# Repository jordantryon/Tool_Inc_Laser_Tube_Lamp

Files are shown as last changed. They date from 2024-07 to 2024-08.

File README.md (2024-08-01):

# Tool., Inc - Laser Tube Lamp
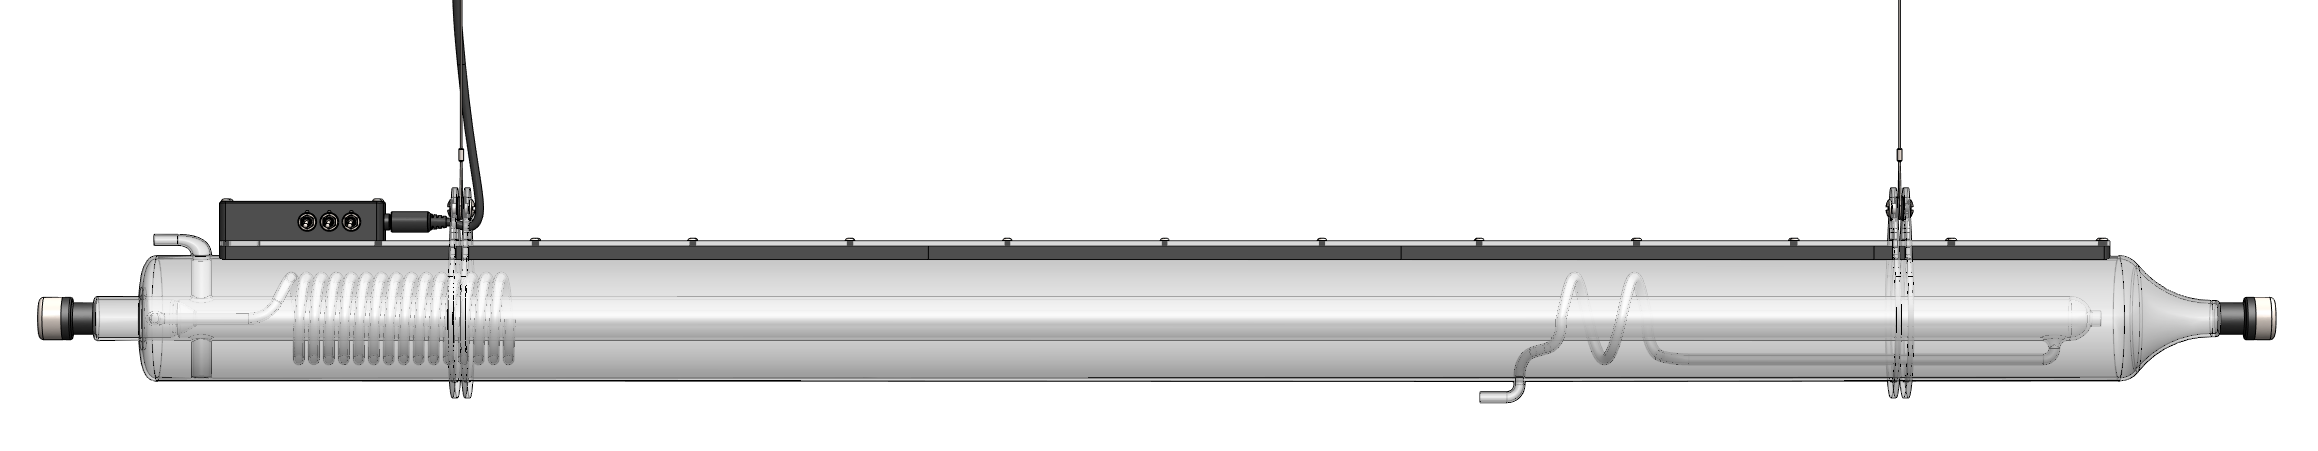
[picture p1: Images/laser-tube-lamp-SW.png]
Laser Tube Lamp SolidWorks


At [Tool., Inc.](https://toolinc.com/) our engineers and designers are constantly using our Lasersaur CNC laser cutter/engraver. Usually to rapidly produce project prototypes but occasionally to make furniture and pieces around the office. Unfortunately, the laser tube that makes the magic happen slowly degrades over time and needs to be replaced. So, what do you do with the old dead tube? It looks super cool so it feels bad to just throw it away. Why not turn it into a unique light fixture?! 

With the new laser tube installed in the machine, we cut a handful of 1/8" acrylic parts and got our Ultimaker 3D printers going on some PLA components. All the hardware is fairly standard and can be found at a local hardware store, or every mechanical engineer's favorite: McMaster-Carr. Using an Arduino and Adafruit NeoPixels, any light can go from plain white to fully custom and dynamic RGB lighting effects in the flick of a switch. Ours uses three toggle switches to select from up to eight preprogrammed lighting modes. We enlisted one of our summer interns to help turn the lighting animations into the 1s and 0s. 

Combine all that with an old 120W, 80mm diameter, 1450mm long, CO2 laser tube and you get a, slightly less destructive, 25W LED lamp. It makes a perfect addition to any shop, makerspace, studio, or employee kitchen and lounge. 

We've open-sourced the project so you too can DIY the most expensive lamp in your shop! This GitHub repository has the instructions, bill of materials, CAD files, and source code. The design was based around our laser tube and equipment but you can adjust it to fit your needs. 

## Lighting Modes
|Switch C|Switch B|Switch A|Mode|
|:---|:---|:---|:---|
|0|0|0|Off|
|0|0|1|Cool White|
|0|1|0|Warm White|
|0|1|1|Wave Bounce|
|1|0|0|Laser Build|
|1|0|1|Breathing Cycle|
|1|1|0|Fill Cycle|
|1|1|1|Rainbow Slide|

## Bill of Materials

### 3D Prints

|Part|File|Quantity|
|:---|:---|:---|
|Electronics Enclosure|electronics_enclosure.stl|1|
|Hanger Cable Pulley|hanger_cable_pully.stl|2|
|Strip (End)|strip_end.stl|2|
|Strip (Side)|strip_side.stl|6|

### Laser Cuts

|Part|File|Quantity|
|:---|:---|:---|
|Strip Backing|strip_back.dxf|1|
|Teardrop Hanger|teardrop_hanger.dxf|4|

### Hardware

|Part|SKU|Quantity|Link|
|:---|:---|:---|:---|
|M3 Heat Set Inserts|94459A140|26|[McMaster-Carr](https://www.mcmaster.com/94459A140/)|
|M3 x 8 mm Button Head Hex Drive Screw|92095A181|22|[McMaster-Carr](https://www.mcmaster.com/92095A181/)|
|M3 x 30 mm Button Head Hex Drive Screw|92095A187|4|[McMaster-Carr](https://www.mcmaster.com/92095A187/)|
|Binding Barrel|98002A202|2|[McMaster-Carr](https://www.mcmaster.com/98002A202/)|
|Wire Rope|3461T474|1|[McMaster-Carr](https://www.mcmaster.com/3461T474/)|
|Wire Rope Compression Sleeve|3896T61|4|[McMaster-Carr](https://www.mcmaster.com/3896T61/)|
|Foam Double Face Mounting Tape|3744A41|1|[McMaster-Carr](https://www.mcmaster.com/3744A41/)|

### Electronics

|Part|SKU|Quantity|Link|Notes|
|:---|:---|:---|:---|:---|
|Arduino Nano Every|ABX00028|1|[Arduino](https://store.arduino.cc/products/arduino-nano-every)|I'd recommend getting the version without headers to solder directly to the Arduino.|
|DC Power Supply (5V, 5A)|B078RT3ZPS|1|[Amazon](https://a.co/d/07ThTM0f)|Each NeoPixel can draw up to 60 mA. For my strip length, that's 4.26 amps!|
|DC Barrel Jack|B07CTCLKPP|1|[Amazon](https://a.co/d/05rNLqdA)||
|Toggle Switch|100SP1T1B1M1QEH|3|[DigiKey](https://www.digikey.com/en/products/detail/e-switch/100SP1T1B1M1QEH/378819)||
|NeoPixel Strip (2 m)|2540|1|[Adafruit](https://www.adafruit.com/product/2540)|To save a couple bucks, buying two 1 m strips can be cheaper.|
|Resistor (470 Ω)|CF14JT470R|1|[DigiKey](https://www.digikey.com/en/products/detail/stackpole-electronics-inc/CF14JT470R/1741440)||
|Capacitor (1,000 μF)|ECA-0JM102|1|[DigiKey](https://www.digikey.com/en/products/detail/panasonic-electronic-components/ECA-0JM102/244974)||

## Images
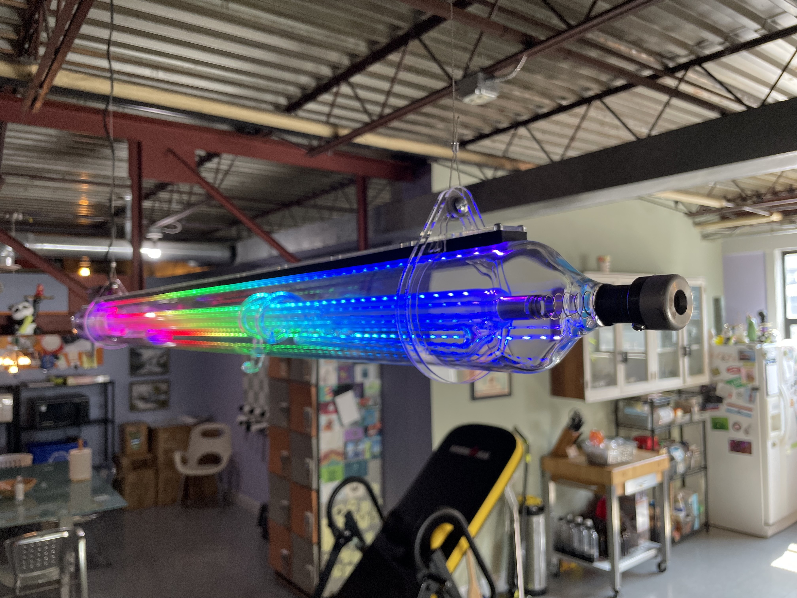
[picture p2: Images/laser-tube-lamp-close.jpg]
Laser Tube Lamp SolidWorks

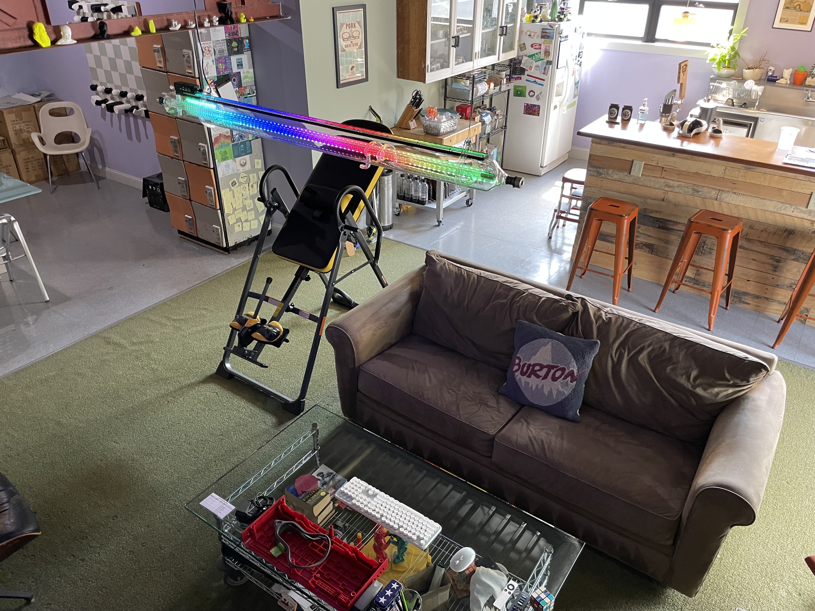
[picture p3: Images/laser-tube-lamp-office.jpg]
Laser Tube Lamp SolidWorks


## Author
Jordan Tryon for tool., Inc.

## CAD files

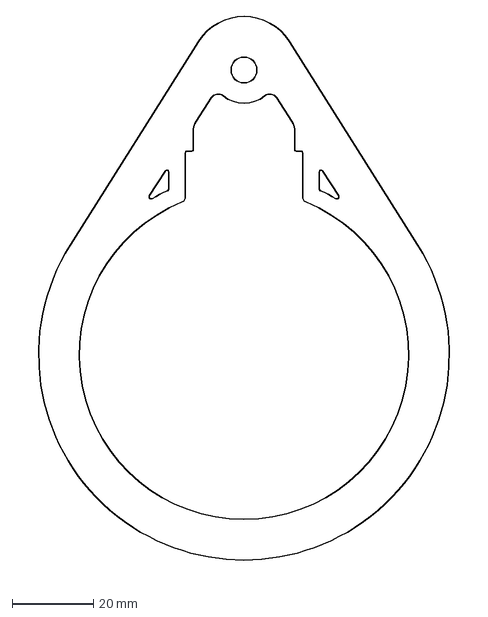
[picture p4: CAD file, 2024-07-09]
DXFs/teardrop_hanger.DXF
112.1 x 137.8 mm

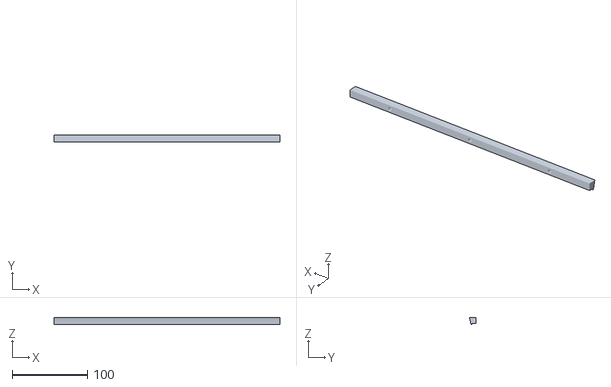
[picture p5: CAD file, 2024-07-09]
STLs/strip_side.STL
300.0 x 8.78 x 9.50

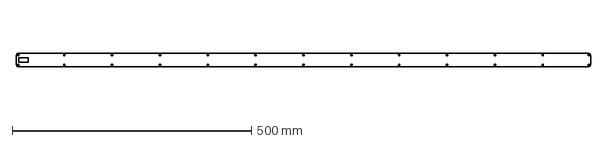
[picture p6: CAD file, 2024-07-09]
DXFs/strip_back.DXF
1200.0 x 28.0 mm

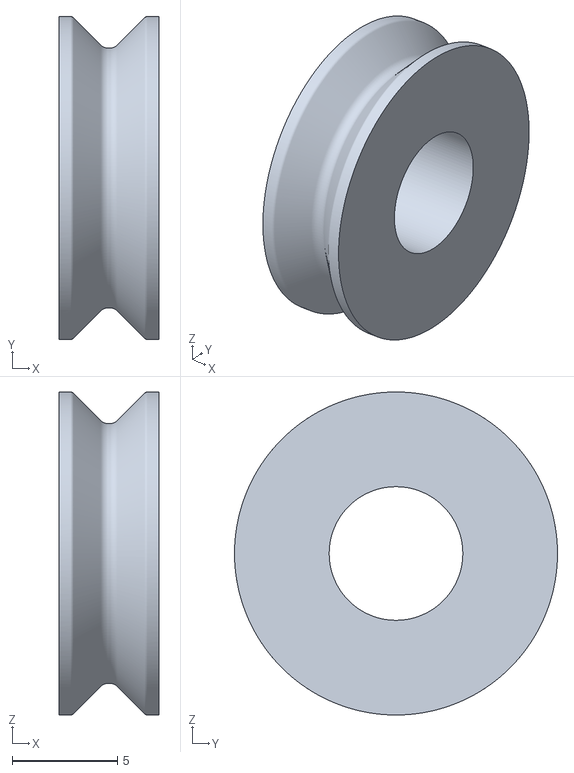
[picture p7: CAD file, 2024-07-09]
STLs/hanger_cable_pully.STL
4.76 x 15.4 x 15.3

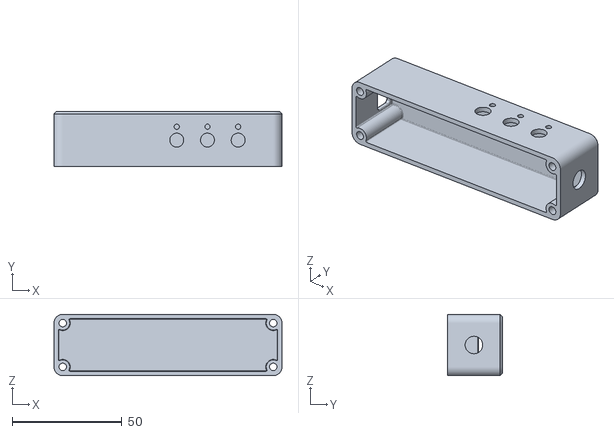
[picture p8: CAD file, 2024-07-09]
STLs/electronics_enclosure.STL
104.0 x 25.0 x 28.0

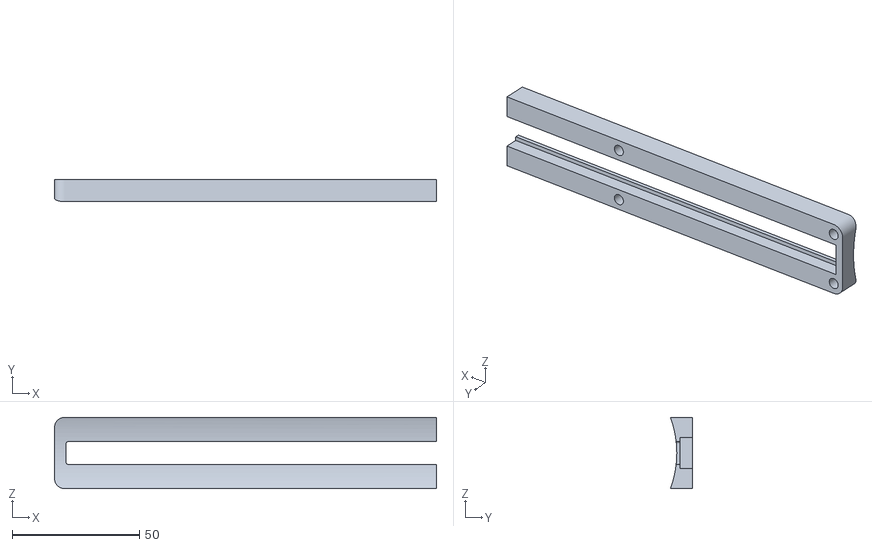
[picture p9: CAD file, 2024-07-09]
STLs/strip_end.STL
150.0 x 8.78 x 28.0

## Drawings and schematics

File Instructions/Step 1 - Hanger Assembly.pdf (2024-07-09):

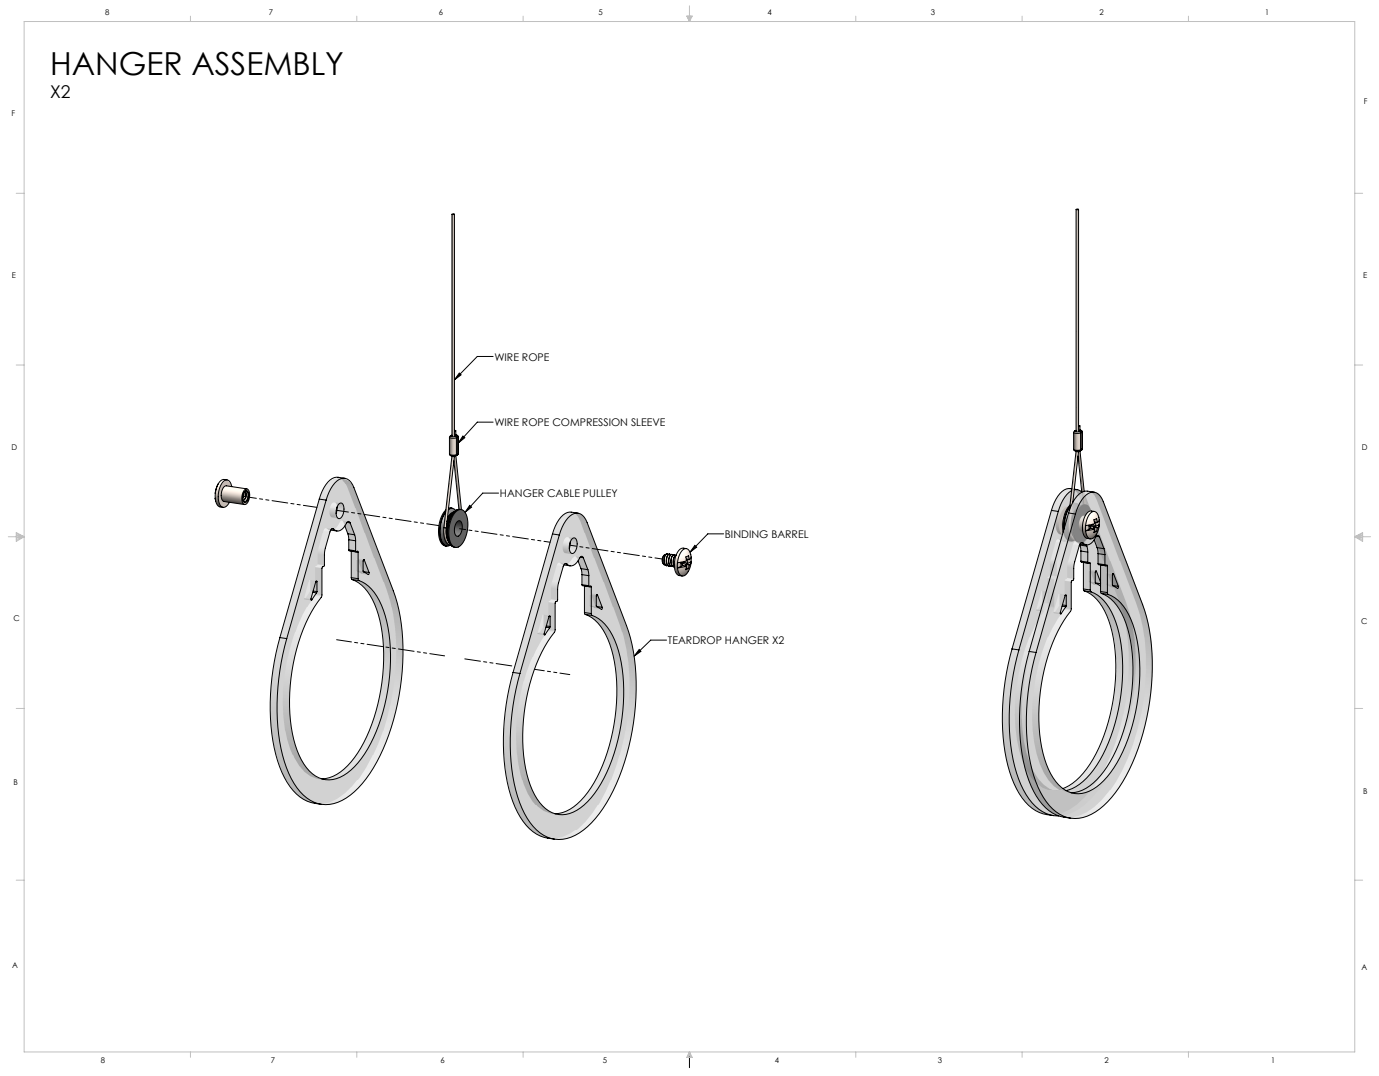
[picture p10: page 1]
WIRE ROPE; BINDING BARREL; TEARDROP HANGER X2; HANGER ASSEMBLY

WIRE ROPE COMPRESSION SLEEVE

HANGER CABLE PULLEY

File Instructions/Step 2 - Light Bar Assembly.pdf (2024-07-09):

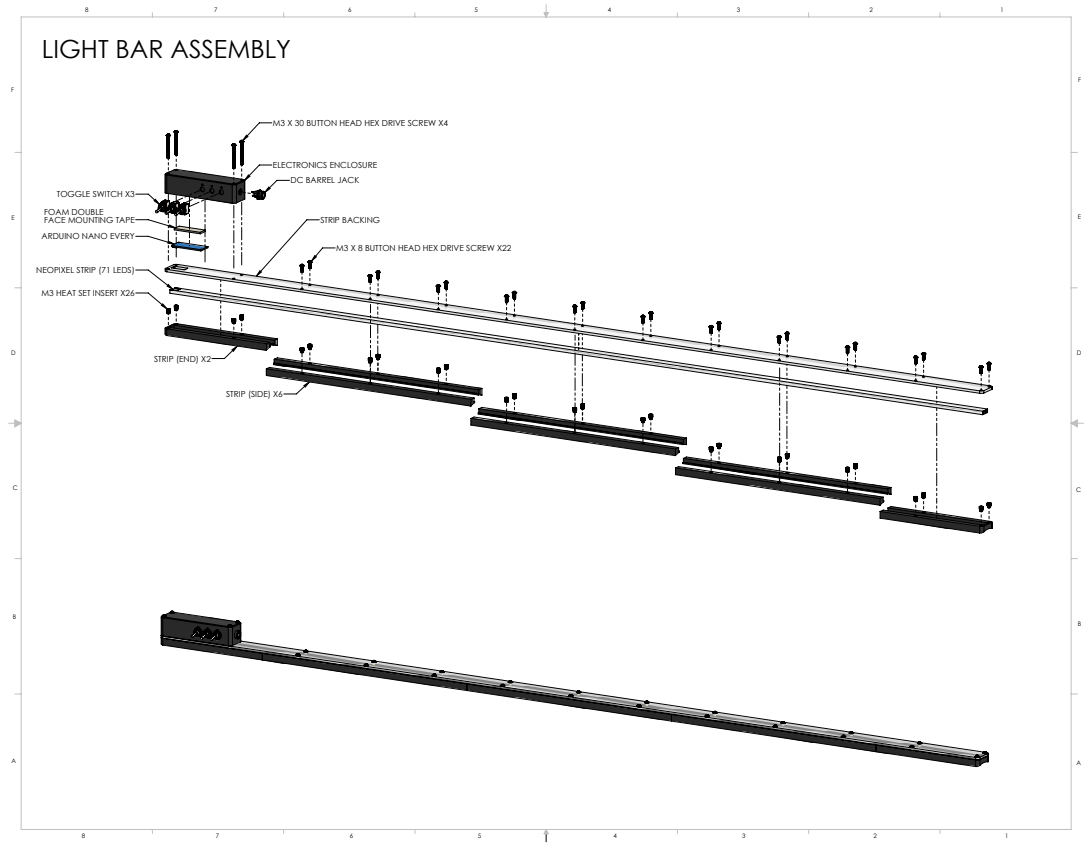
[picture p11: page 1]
STRIP BACKING; STRIP (SIDE) X6; STRIP (END) X2

LIGHT BAR ASSEMBLY

M3 X 30 BUTTON HEAD HEX DRIVE SCREW X4

ELECTRONICS ENCLOSURE
DC BARREL JACK

TOGGLE SWITCH X3
FOAM DOUBLE
FACE MOUNTING TAPE
ARDUINO NANO EVERY

M3 X 8 BUTTON HEAD HEX DRIVE SCREW X22

NEOPIXEL STRIP (71 LEDS)

M3 HEAT SET INSERT X26

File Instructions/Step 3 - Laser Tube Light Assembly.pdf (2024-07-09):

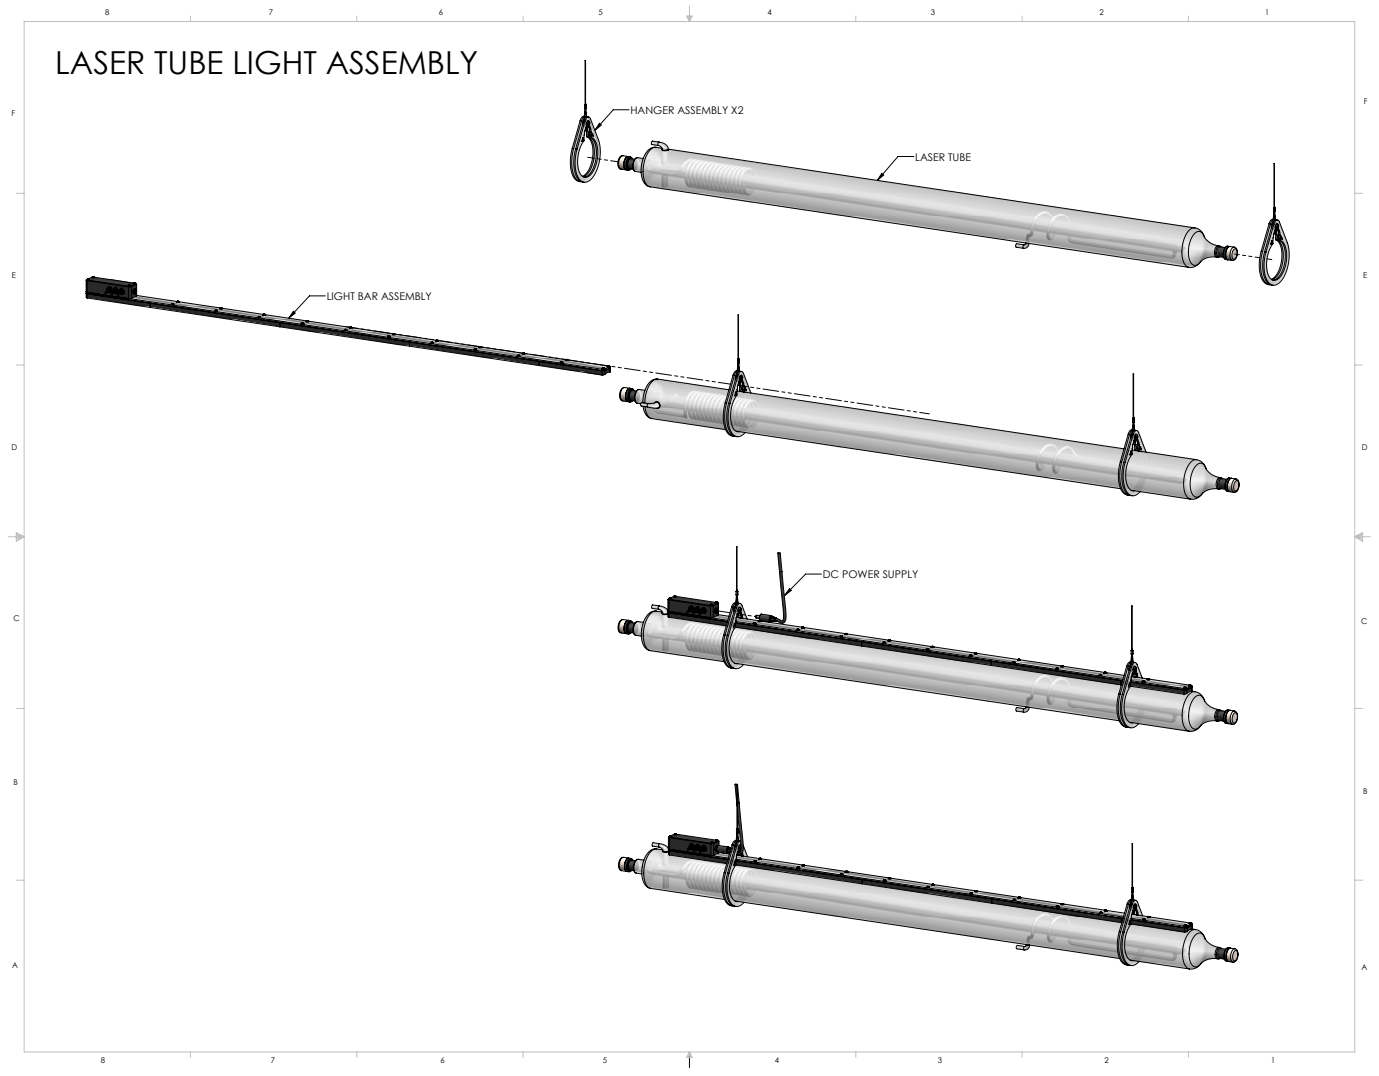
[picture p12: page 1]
HANGER ASSEMBLY X2; LASER TUBE

LASER TUBE LIGHT ASSEMBLY

LIGHT BAR ASSEMBLY

DC POWER SUPPLY

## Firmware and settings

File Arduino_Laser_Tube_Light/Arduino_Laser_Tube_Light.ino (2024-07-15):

// Author: Jordan Tryon - tool., Inc.
// Modified: 7/15/2024
// Project: Laser Tube Light
// Description: Arduino code for controlling a NeoPixel strip lighting fixture. 

// -------------------------------------- INCLUDE LIBRARIES -------------------------------------- //

#include <Adafruit_NeoPixel.h>

// --------------------------------------- PIN DEFINITIONS --------------------------------------- //

// Define input pins
#define pin_switch_a 2
#define pin_switch_b 3
#define pin_switch_c 4

// Define NeoPixel strip pin
#define pin_neopixel 5

// -------------------------------------- PROGRAM VARIABLES -------------------------------------- //

// Button & Switch Inputs
const int debounce_time = 10;

// NeoPixel
const int num_pixels = 71;
Adafruit_NeoPixel strip(num_pixels, pin_neopixel, NEO_GRB + NEO_KHZ800);

// Control
bool val_a = LOW;
bool val_b = LOW;
bool val_c = LOW;

// ----------------------------------- STATE MACHINE VARIABLES ----------------------------------- //

int state_switch_a = 2;
int state_switch_b = 2;
int state_switch_c = 2;

// ------------------------------------- Timers & Timestamps ------------------------------------- //

unsigned long t = 0;
unsigned long t_0 = 0;
unsigned long t_switch_a = 0;
unsigned long t_0_switch_a = 0;
unsigned long t_switch_b = 0;
unsigned long t_0_switch_b = 0;
unsigned long t_switch_c = 0;
unsigned long t_0_switch_c = 0;

// ----------------------------------------- SETUP LOOP ------------------------------------------ //

void setup(){
  // Wait for initial power-on
  delay(1000);
  
  // Initialize input pins
  pinMode(pin_switch_a, INPUT);
  pinMode(pin_switch_b, INPUT);
  pinMode(pin_switch_c, INPUT);

  // Initialize the NeoPixel object
  strip.begin();
  strip.setBrightness(255);
  strip.clear();
  strip.show();
  
  // Begin serial communication
  Serial.begin(115200);
}

// ---------------------------------------- PROGRAM LOOP ----------------------------------------- //

void loop(){
  // Wait to update the lighting mode, prevents repeatedly calling blocking functions after switches change position
  t_0 = millis();
  t = millis();
  while(t - t_0 <= 20){
    t = millis();
    SM_switch_a();
    SM_switch_b();
    SM_switch_c();
  }

  // Off
  if(val_c == LOW && val_b == LOW && val_a == LOW){
    strip.clear();
    strip.show();
  }

  // On - Cool White
  if(val_c == LOW && val_b == LOW && val_a == HIGH){
    strip_fill(255, 255, 255);
  }

  // On - Warm White
  if(val_c == LOW && val_b == HIGH && val_a == LOW){
    strip_fill(255, 100, 10);
  }

  // On - Wave Bounce
  if(val_c == LOW && val_b == HIGH && val_a == HIGH){
    wave_bounce(255, 100, 10);
  }

  // On - Laser Build
  if(val_c == HIGH && val_b == LOW && val_a == LOW){
    laser_build(255, 100, 10);
  }

  // On - Breathing Cycle
  if(val_c == HIGH && val_b == LOW && val_a == HIGH){
    breathing_cycle();
  }

  // On - Fill Cycle
  if(val_c == HIGH && val_b == HIGH && val_a == LOW){
    fill_cycle();
  }

  // On - Rainbow Slide
  if(val_c == HIGH && val_b == HIGH && val_a == HIGH){
    rainbow_slide();
  }
}

// --------------------------------------- STATE MACHINES ---------------------------------------- //

// State machine to debounce switch a
void SM_switch_a(){
  bool currentVal = digitalRead(pin_switch_a);
  
  switch(state_switch_a){
    case 0: // 0 - Wait for LOW
      if(currentVal == LOW){
        t_0_switch_a = millis();
        state_switch_a = 1;
      }
    break;
    
    case 1: // 1 - Debounce
      t_switch_a = millis();
      if(currentVal == HIGH){ state_switch_a = 0; }
      if(t_switch_a - t_0_switch_a >= debounce_time){ state_switch_a = 2; }
    break;
    
    case 2: // 2 - Trigger LOW
      val_a = LOW;
      state_switch_a = 3;
    break;
    
    case 3: // 3 - Wait for HIGH
      if(currentVal == HIGH){
        t_0_switch_a = millis();
        state_switch_a = 4;
      }
    break;
    
    case 4: // 4 - Debounce
      t_switch_a = millis();
      if(currentVal == LOW){ state_switch_a = 3; }
      if(t_switch_a - t_0_switch_a >= debounce_time){ state_switch_a = 5; }
    break;
    
    case 5: // 5 - Trigger HIGH
      val_a = HIGH;
      state_switch_a = 0;
    break;
    
    default:
    break;
  }
}

// State machine to debounce switch b
void SM_switch_b(){
  bool currentVal = digitalRead(pin_switch_b);
  
  switch(state_switch_b){
    case 0: // 0 - Wait for LOW
      if(currentVal == LOW){
        t_0_switch_b = millis();
        state_switch_b = 1;
      }
    break;
    
    case 1: // 1 - Debounce
      t_switch_b = millis();
      if(currentVal == HIGH){ state_switch_b = 0; }
      if(t_switch_b - t_0_switch_b >= debounce_time){ state_switch_b = 2; }
    break;
    
    case 2: // 2 - Trigger LOW
      val_b = LOW;
      state_switch_b = 3;
    break;
    
    case 3: // 3 - Wait for HIGH
      if(currentVal == HIGH){
        t_0_switch_b = millis();
        state_switch_b = 4;
      }
    break;
    
    case 4: // 4 - Debounce
      t_switch_b = millis();
      if(currentVal == LOW){ state_switch_b = 3; }
      if(t_switch_b - t_0_switch_b >= debounce_time){ state_switch_b = 5; }
    break;
    
    case 5: // 5 - Trigger HIGH
      val_b = HIGH;
      state_switch_b = 0;
    break;
    
    default:
    break;
  }
}

// State machine to debounce switch c
void SM_switch_c(){
  bool currentVal = digitalRead(pin_switch_c);
  
  switch(state_switch_c){
    case 0: // 0 - Wait for LOW
      if(currentVal == LOW){
        t_0_switch_c = millis();
        state_switch_c = 1;
      }
    break;
    
    case 1: // 1 - Debounce
      t_switch_c = millis();
      if(currentVal == HIGH){ state_switch_c = 0; }
      if(t_switch_c - t_0_switch_c >= debounce_time){ state_switch_c = 2; }
    break;
    
    case 2: // 2 - Trigger LOW
      val_c = LOW;
      state_switch_c = 3;
    break;
    
    case 3: // 3 - Wait for HIGH
      if(currentVal == HIGH){
        t_0_switch_c = millis();
        state_switch_c = 4;
      }
    break;
    
    case 4: // 4 - Debounce
      t_switch_c = millis();
      if(currentVal == LOW){ state_switch_c = 3; }
      if(t_switch_c - t_0_switch_c >= debounce_time){ state_switch_c = 5; }
    break;
    
    case 5: // 5 - Trigger HIGH
      val_c = HIGH;
      state_switch_c = 0;
    break;
    
    default:
    break;
  }
}

// ------------------------------------------ FUNCTIONS ------------------------------------------ //

void strip_fill(int r, int g, int b){
  for(int i = 0; i < num_pixels; i++){
    strip.setPixelColor(i, strip.Color(r, g, b));
  }
  strip.show();
}

void fill_cycle(){
  fill_cycle(10);
}

void fill_cycle(unsigned long d){
  int r = 255;
  int g = 0;
  int b = 0;

  for(int i = 0; i <= 255; i++){
    g = i;
    strip_fill(r, g, b);
    delay(d);
  }
  for(int i = 255; i >= 0; i--){
    r = i;
    strip_fill(r, g, b);
    delay(d);
  }
  for(int i = 0; i <= 255; i++){
    b = i;
    strip_fill(r, g, b);
    delay(d);
  }
  for(int i = 255; i >= 0; i--){
    g = i;
    strip_fill(r, g, b);
    delay(d);
  }
  for(int i = 0; i <= 255; i++){
    r = i;
    strip_fill(r, g, b);
    delay(d);
  }
  for(int i = 255; i >= 0; i--){
    b = i;
    strip_fill(r, g, b);
    delay(d);
  }
}

void breathing_cycle(){
  breathing_cycle(10);
}

void breathing_cycle(unsigned long d){
  int r = 0;
  int g = 0;
  int b = 0;

  for(int i = 0; i <= 255; i++){
    r = i;
    strip_fill(r, g, b);
    delay(d);
  }
  for(int i = 255; i >= 0; i--){
    r = i;
    strip_fill(r, g, b);
    delay(d);
  }
  for(int i = 0; i <= 255; i++){
    r = i;
    g = i;
    strip_fill(r, g, b);
    delay(d);
  }
  for(int i = 255; i >= 0; i--){
    r = i;
    g = i;
    strip_fill(r, g, b);
    delay(d);
  }
  for(int i = 0; i <= 255; i++){
    g = i;
    strip_fill(r, g, b);
    delay(d);
  }
  for(int i = 255; i >= 0; i--){
    g = i;
    strip_fill(r, g, b);
    delay(d);
  }
  for(int i = 0; i <= 255; i++){
    g = i;
    b = i;
    strip_fill(r, g, b);
    delay(d);
  }
  for(int i = 255; i >= 0; i--){
    g = i;
    b = i;
    strip_fill(r, g, b);
    delay(d);
  }
  for(int i = 0; i <= 255; i++){
    b = i;
    strip_fill(r, g, b);
    delay(d);
  }
  for(int i = 255; i >= 0; i--){
    b = i;
    strip_fill(r, g, b);
    delay(d);
  }
  for(int i = 0; i <= 255; i++){
    b = i;
    r = i;
    strip_fill(r, g, b);
    delay(d);
  }
  for(int i = 255; i >= 0; i--){
    b = i;
    r = i;
    strip_fill(r, g, b);
    delay(d);
  }
}

void block_bounce(int r, int g, int b){
  block_bounce(r, g, b, 10, 30);
}

void block_bounce(int r, int g, int b, int L){
  block_bounce(r, g, b, L, 30);
}

void block_bounce(int r, int g, int b, int L, unsigned long d){
  // Send pixels up the strip
  for(int i = 0; i <= num_pixels - L; i++){
    // Turn on pixels
    for(int j = 0; j < L; j++){
      strip.setPixelColor(i + j, strip.Color(r, g, b));
    }
    // Turn off trailing pixel
    if(i > 0){
      strip.setPixelColor(i - 1, strip.Color(0, 0, 0));
    }
    strip.show();
    delay(d);
  }

  // Send pixels down the strip
  for(int i = num_pixels - L; i >= 0; i--){
    // Turn on pixels
    for(int j = 0; j < L; j++){
      strip.setPixelColor(i + j, strip.Color(r, g, b));
    }
    // Turn off trailing pixel
    if(i + L < num_pixels){
      strip.setPixelColor(i + L, strip.Color(0, 0, 0));
    }
    strip.show();
    delay(d);
  }
}

void wave_bounce(int r, int g, int b){
  wave_bounce(r, g, b, 15, 30);
}

void wave_bounce(int r, int g, int b, int L){
  wave_bounce(r, g, b, L, 30);
}

void wave_bounce(int r, int g, int b, int L, unsigned long d){
  // Calculate mid point
  int mid = L/2;

  // Send pixels up the strip
  for(int i = -mid; i <= num_pixels - mid - 1; i++){
    // Turn on pixels
    for(int j = 0; j < L; j++){
      // Exp map | y = e^(-(x^2)) | the domain from 0 to 2 looks good
      float x = abs(j-mid)/(float)mid*2.0;
      float y = exp(-pow(x,2));
      int r_map = r*y;
      int g_map = g*y;
      int b_map = b*y;
      strip.setPixelColor(i + j, strip.Color(r_map, g_map, b_map));
    }
    // Turn off trailing pixel
    if(i > 0){
      strip.setPixelColor(i - 1, strip.Color(0, 0, 0));
    }
    strip.show();
    delay(d);
  }

  // Send pixels down the strip
  for(int i = num_pixels - mid - 1; i >= -mid; i--){
    // Turn on pixels
    for(int j = 0; j < L; j++){
      // Exp map | y = e^(-(x^2)) | the domain from 0 to 2 looks good
      float x = abs(j-mid)/(float)mid*2.0;
      float y = exp(-pow(x,2));
      int r_map = r*y;
      int g_map = g*y;
      int b_map = b*y;
      strip.setPixelColor(i + j, strip.Color(r_map, g_map, b_map));
    }
    // Turn off trailing pixel
    if(i + L < num_pixels){
      strip.setPixelColor(i + L, strip.Color(0, 0, 0));
    }
    strip.show();
    delay(d);
  }
}

void laser_build(int r, int g, int b){
  laser_build(r, g, b, 3);
}

void laser_build(int r, int g, int b, unsigned long d){
  // Build the strip
  for(int i = num_pixels; i > 0; i--){
    for(int j = 0; j < i; j++){
      strip.setPixelColor(j, strip.Color(r, g, b));
      if(j > 0){
        strip.setPixelColor(j - 1, strip.Color(0, 0, 0));
      }
      strip.show();
      delay(d);
    }
    delay(d*100);
  }

  // Clear the strip
  for(int i = 0; i < num_pixels; i++){
    strip.setPixelColor(i, strip.Color(0, 0, 0));
    strip.show();
    delay(d);
  }
  delay(d*100);
}

void rainbow_slide(){
  rainbow_slide(15);
}

void rainbow_slide(unsigned long d){
  uint16_t max_val = 65535;
  uint16_t step_size = 100;
  uint16_t step_count = max_val/step_size;
  
  for(uint16_t i = 0; i <= step_count; i++){
    strip.rainbow(i*step_size, 1);
    strip.show();
    delay(d);
  }
}

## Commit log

2024-07-09 Add Documentation
    [electronics_enclosure.STL, hanger_cable_pully.STL, strip_back.DXF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]
2024-07-15 Lighting effect delay fix
    [Arduino_Laser_Tube_Light.ino]
